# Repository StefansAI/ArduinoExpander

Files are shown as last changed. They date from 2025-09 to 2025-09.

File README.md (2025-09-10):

<h1 style="text-align: center;">ArduinoExpander</h1>
<h2 style="text-align: center;">IO Expander for Arduino Uno</h2>
<br>
<div style="text-align: center;">
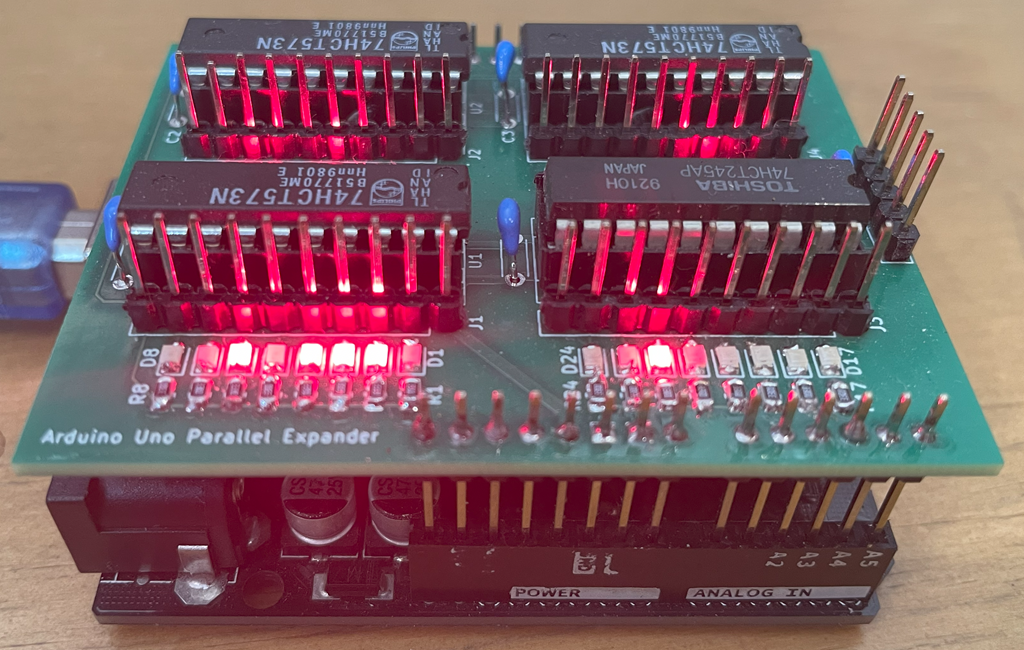
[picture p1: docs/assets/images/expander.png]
  
</div>
<br>
This IO expander plugs into an Arduino Uno to add more controllable pins. It can be used for instance to interact with TTL circuits. One configuration can be 24 bits output and 8 bit bi-directional. Replacing the 74HCT245 chip with a 74HCT573 will give 32 bits output only.
<br><br>
<div style="text-align: center;">
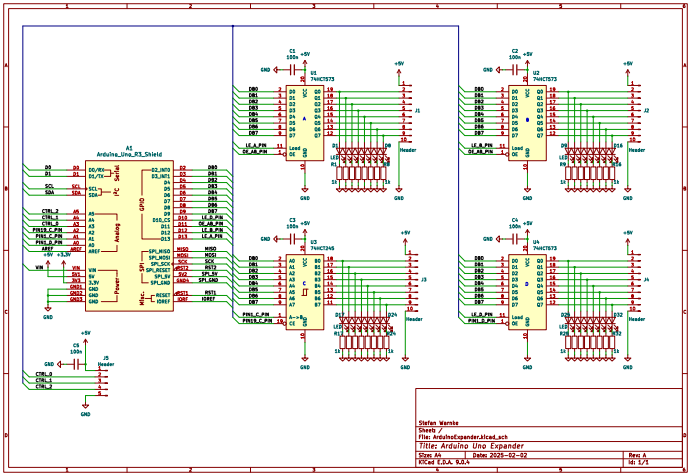
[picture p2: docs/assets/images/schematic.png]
  
</div>
<br>
The schematic and layout are design with KiCad 9.
<br><br>
<div style="text-align: center;">
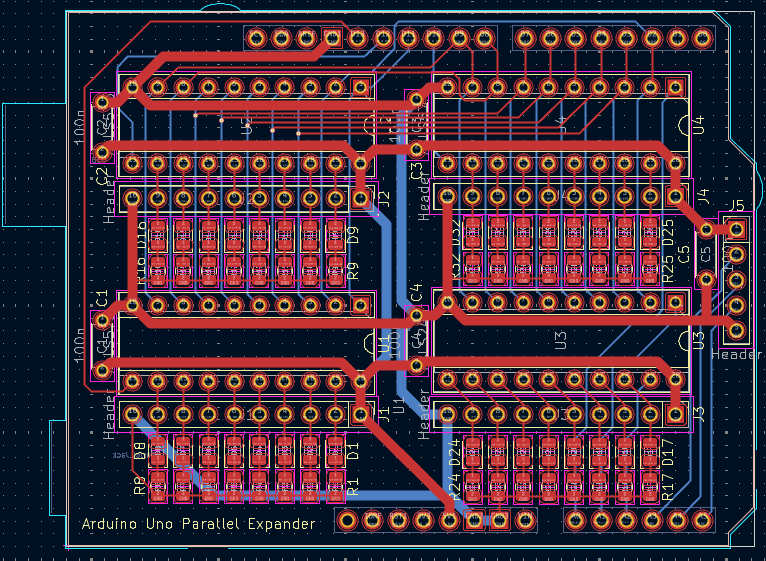
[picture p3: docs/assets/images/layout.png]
  
</div>
<br>

The repository contains an example code to test a RAM chip on a breadboard connected to the expander as address bus, databus and control signals.

<br><br>
<div style="text-align: center;">
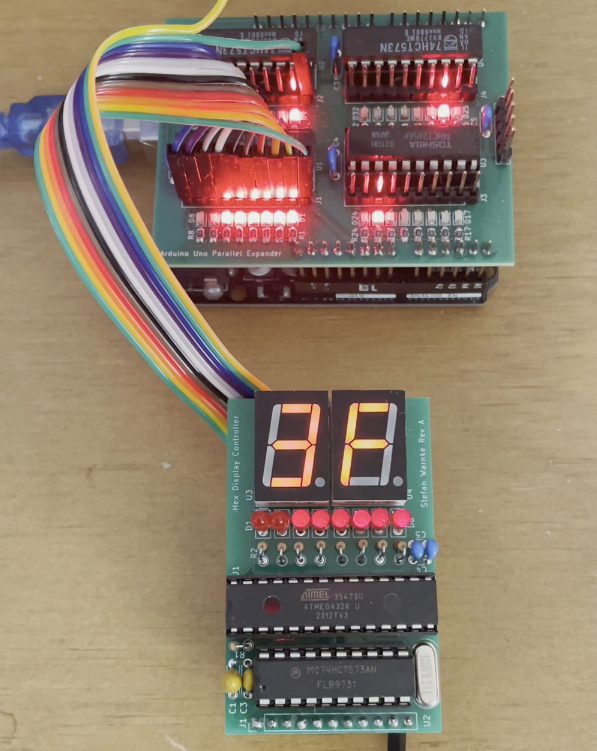
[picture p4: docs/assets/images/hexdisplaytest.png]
  
</div>
<br>
Here is an example to test the HexDisplayController.

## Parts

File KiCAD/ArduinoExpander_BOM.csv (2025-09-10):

Reference | Value | Datasheet | Footprint | Qty | DNP | OrderInfo
A1 | Arduino_Uno_R3_Shield | https://docs.arduino.cc/hardware/uno-rev3 | footprints:Arduino_Uno_R3_Shield | 1 |  | https://www.amazon.com/ELEGOO-Board-ATmega328P-ATMEGA16U2-Compliant/dp/B01EWOE0UU?s=industrial
C1,C2,C3,C4,C5 | 100n | ~ | Capacitor_THT:C_Disc_D4.3mm_W1.9mm_P5.00mm | 5 |  | https://www.digikey.com/en/products/detail/kemet/C320C104M5R5TA/3726028
D1,D2,D3,D4,D5,D6,D7,D8,D9,D10,D11,D12,D13,D14,D15,D16,D17,D18,D19,D20,D21,D22,D23,D24,D25,D26,D27,D28,D29,D30,D31,D32 | LED | ~ | LED_SMD:LED_0805_2012Metric | 32 |  | https://www.digikey.com/en/products/detail/harvatek-corporation/B1701URO-20D000114U1930/16671739
J1,J2,J3,J4,J5 | Header | ~ | Connector_PinHeader_2.54mm:PinHeader_1x05_P2.54mm_Vertical,Connector_PinHeader_2.54mm:PinHeader_1x10_P2.54mm_Vertical | 5
R1,R2,R3,R4,R5,R6,R7,R8,R9,R10,R11,R12,R13,R14,R15,R16,R17,R18,R19,R20,R21,R22,R23,R24,R25,R26,R27,R28,R29,R30,R31,R32 | 1k | ~ | Resistor_SMD:R_0805_2012Metric | 32 |  | https://www.digikey.com/en/products/detail/yageo/RC0805FR-071KL/727444
U1,U2,U4 | 74HCT573 | 74xx/74hc573.pdf | Package_DIP:DIP-20_W7.62mm_Socket | 3 |  | https://www.digikey.com/en/products/detail/texas-instruments/CD74HCT573E/38717
U3 | 74HCT245 | http://www.ti.com/lit/gpn/sn74LS245 | Package_DIP:DIP-20_W7.62mm_Socket | 1 |  | https://www.digikey.com/en/products/detail/texas-instruments/SN74HCT245N/277258

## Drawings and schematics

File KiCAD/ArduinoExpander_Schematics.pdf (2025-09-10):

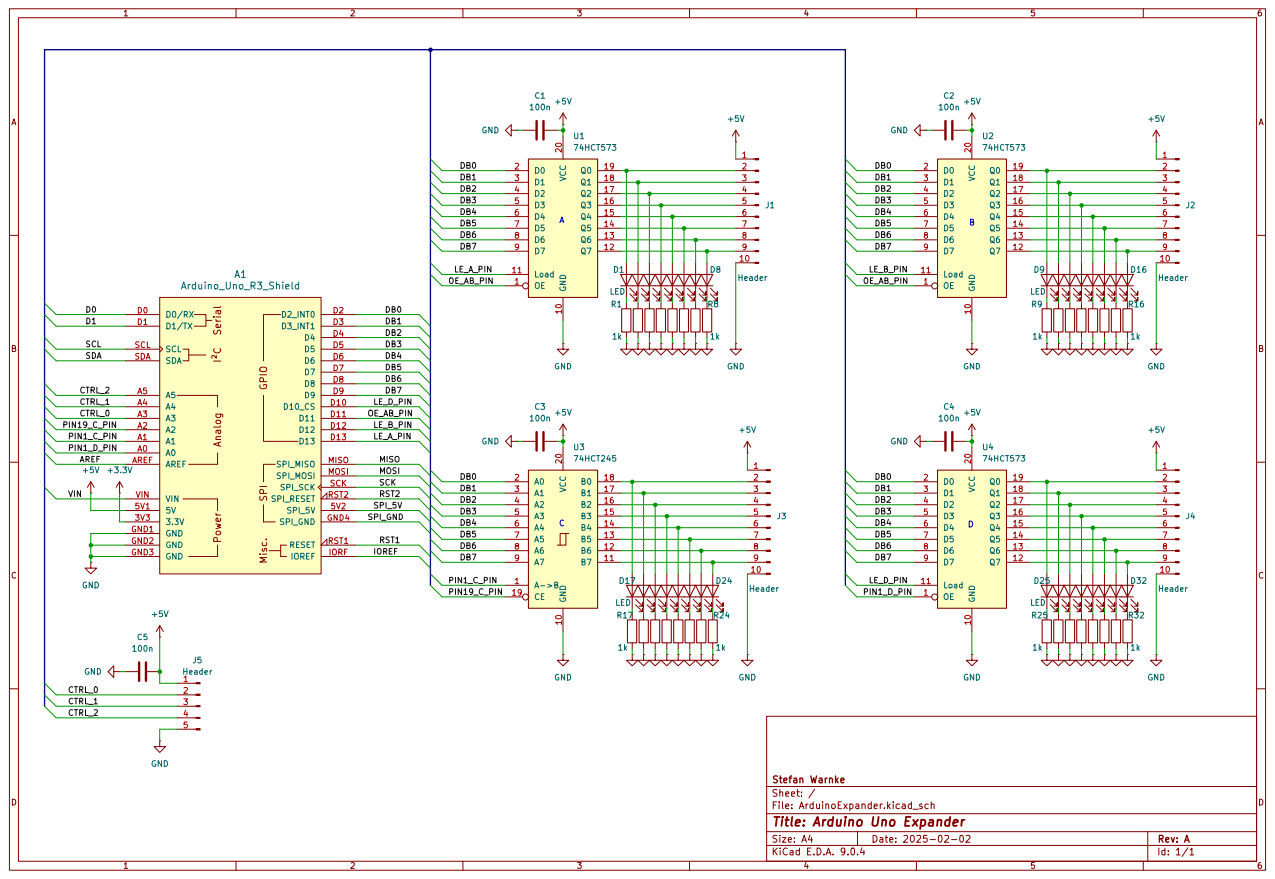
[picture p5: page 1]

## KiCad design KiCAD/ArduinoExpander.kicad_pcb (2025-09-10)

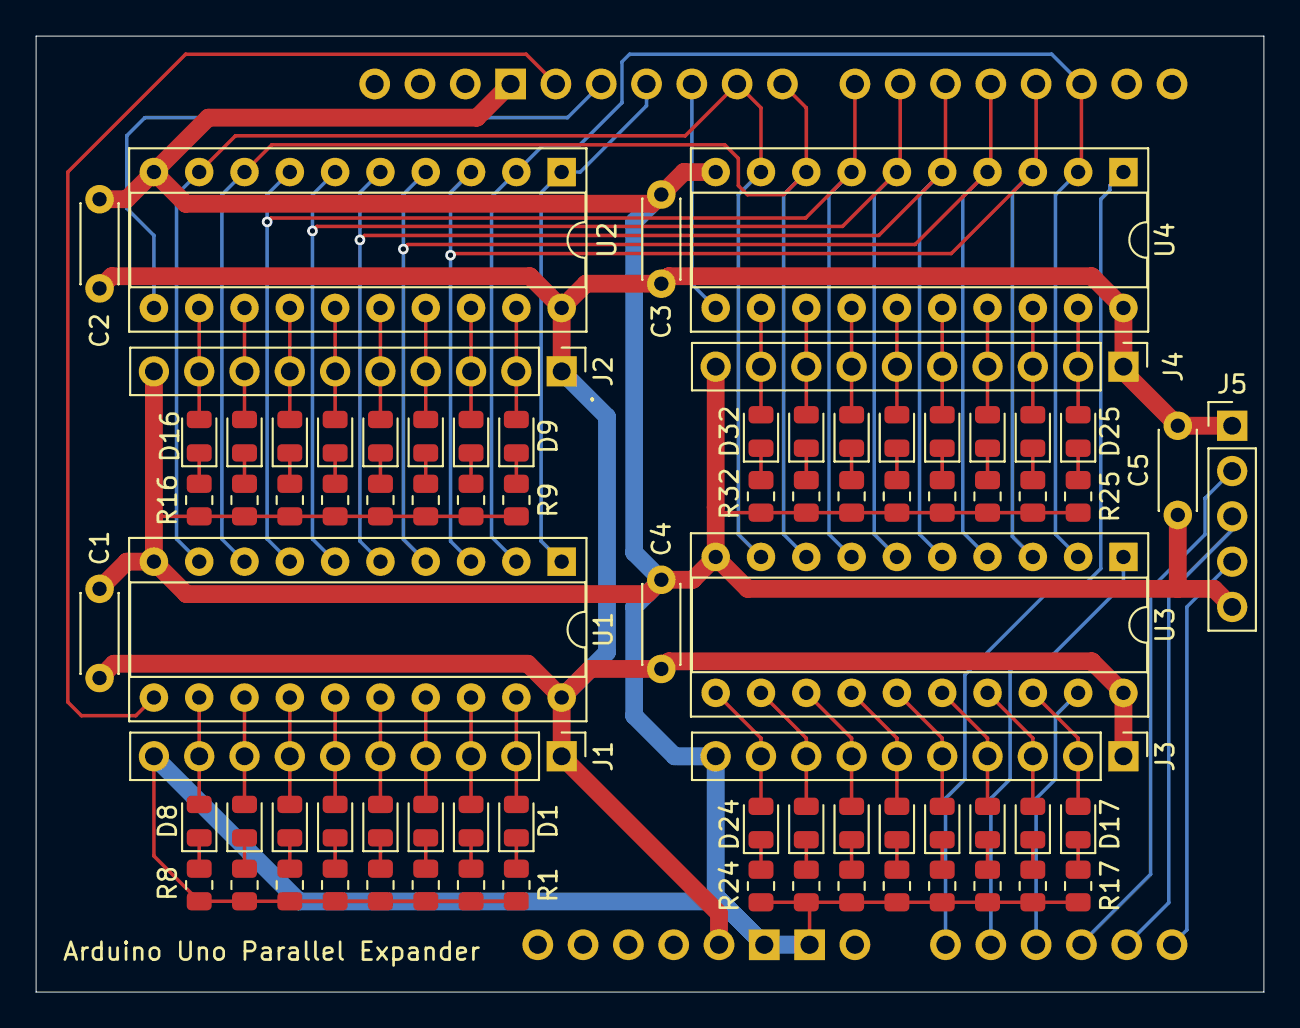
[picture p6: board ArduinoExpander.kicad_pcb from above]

Board: 2 copper layers, 68.8 x 53.6 mm, 79 parts (0 on the bottom side), 84 nets.

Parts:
A1: Arduino_Uno_R3_Shield
C1, C2, C3, C4, C5: 100n; C_Disc_D4.3mm_W1.9mm_P5.00mm
D1, D2, D3, D4, D5, D6, D7, D8, D9, D10, D11, D12, D13, D14, D15, D16, D17, D18, D19, D20, D21, D22, D23, D24, D25, D26, D27, D28, D29, D30, D31, D32: LED; LED_0805_2012Metric
J1, J2, J3, J4: Header; PinHeader_1x10_P2.54mm_Vertical
J5: Header; PinHeader_1x05_P2.54mm_Vertical
R1, R2, R3, R4, R5, R6, R7, R8, R9, R10, R11, R12, R13, R14, R15, R16, R17, R18, R19, R20, R21, R22, R23, R24, R25, R26, R27, R28, R29, R30, R31, R32: 1k; R_0805_2012Metric
U1, U2, U4: 74LS573; DIP-20_W7.62mm_Socket
U3: 74LS245; DIP-20_W7.62mm_Socket

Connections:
+5V: A1.5V1 (5V), C1.2, C2.2, C3.2, C4.2, C5.2, J1.1, J2.1, J3.1, J4.1, J5.1, U1.20 (VCC), U2.20 (VCC), U3.20 (VCC), U4.20 (VCC)
/CTRL_0: A1.A3, J5.2
/CTRL_1: A1.A4, J5.3
/CTRL_2: A1.A5, J5.4
/DB0: A1.D2 (D2_INT0), U1.2 (D0), U2.2 (D0), U3.2 (A0), U4.2 (D0)
/DB1: A1.D3 (D3_INT1), U1.3 (D1), U2.3 (D1), U3.3 (A1), U4.3 (D1)
/DB2: A1.D4, U1.4 (D2), U2.4 (D2), U3.4 (A2), U4.4 (D2)
/DB3: A1.D5, U1.5 (D3), U2.5 (D3), U3.5 (A3), U4.5 (D3)
/DB4: A1.D6, U1.6 (D4), U2.6 (D4), U3.6 (A4), U4.6 (D4)
/DB5: A1.D7, U1.7 (D5), U2.7 (D5), U3.7 (A5), U4.7 (D5)
/DB6: A1.D8, U1.8 (D6), U2.8 (D6), U3.8 (A6), U4.8 (D6)
/DB7: A1.D9, U1.9 (D7), U2.9 (D7), U3.9 (A7), U4.9 (D7)
/LE_A_PIN: A1.D13, U1.11 (Load)
/LE_B_PIN: A1.D12, U2.11 (Load)
/LE_D_PIN: A1.D10 (D10_CS), U4.11 (Load)
/OE_AB_PIN: A1.D11, U1.1 (OE), U2.1 (OE)
/PIN1_C_PIN: A1.A1, U3.1 (A->B)
/PIN1_D_PIN: A1.A0, U4.1 (OE)
/PIN19_C_PIN: A1.A2, U3.19 (CE)
GND: A1.GND1 (GND), A1.GND2 (GND), A1.GND3 (GND), C1.1, C2.1, C3.1, C4.1, C5.1, J1.10, J2.10, J3.10, J4.10, J5.5, R1.2, R2.2, R3.2, R4.2, R5.2, R6.2, R7.2, R8.2, R9.2, R10.2, R11.2, R12.2, R13.2, R14.2, R15.2, R16.2, R17.2, R18.2, R19.2, R20.2, R21.2, R22.2, R23.2, R24.2, R25.2, R26.2, R27.2, R28.2, R29.2, R30.2, R31.2, R32.2, U1.10 (GND), U2.10 (GND), U3.10 (GND), U4.10 (GND)
unnamed: D1.2 (A), J1.2, U1.19 (Q0)
unnamed: D1.1 (K), R1.1
unnamed: D2.2 (A), J1.3, U1.18 (Q1)
unnamed: D2.1 (K), R2.1
unnamed: D3.2 (A), J1.4, U1.17 (Q2)
unnamed: D3.1 (K), R3.1
unnamed: D4.2 (A), J1.5, U1.16 (Q3)
unnamed: D4.1 (K), R4.1
unnamed: D5.2 (A), J1.6, U1.15 (Q4)
unnamed: D5.1 (K), R5.1
unnamed: D6.2 (A), J1.7, U1.14 (Q5)
unnamed: D6.1 (K), R6.1
unnamed: D7.2 (A), J1.8, U1.13 (Q6)
unnamed: D7.1 (K), R7.1
unnamed: D8.2 (A), J1.9, U1.12 (Q7)
unnamed: D8.1 (K), R8.1
unnamed: D9.2 (A), J2.2, U2.19 (Q0)
unnamed: D9.1 (K), R9.1
unnamed: D10.2 (A), J2.3, U2.18 (Q1)
unnamed: D10.1 (K), R10.1
unnamed: D11.2 (A), J2.4, U2.17 (Q2)
unnamed: D11.1 (K), R11.1
unnamed: D12.2 (A), J2.5, U2.16 (Q3)
unnamed: D12.1 (K), R12.1
unnamed: D13.2 (A), J2.6, U2.15 (Q4)
unnamed: D13.1 (K), R13.1
unnamed: D14.2 (A), J2.7, U2.14 (Q5)
unnamed: D14.1 (K), R14.1
unnamed: D15.2 (A), J2.8, U2.13 (Q6)
unnamed: D15.1 (K), R15.1
unnamed: D16.2 (A), J2.9, U2.12 (Q7)
unnamed: D16.1 (K), R16.1
unnamed: D17.2 (A), J3.2, U3.18 (B0)
unnamed: D17.1 (K), R17.1
unnamed: D18.2 (A), J3.3, U3.17 (B1)
unnamed: D18.1 (K), R18.1
unnamed: D19.2 (A), J3.4, U3.16 (B2)
unnamed: D19.1 (K), R19.1
unnamed: D20.2 (A), J3.5, U3.15 (B3)
unnamed: D20.1 (K), R20.1
unnamed: D21.2 (A), J3.6, U3.14 (B4)
unnamed: D21.1 (K), R21.1
unnamed: D22.2 (A), J3.7, U3.13 (B5)
unnamed: D22.1 (K), R22.1
unnamed: D23.2 (A), J3.8, U3.12 (B6)
unnamed: D23.1 (K), R23.1
unnamed: D24.2 (A), J3.9, U3.11 (B7)
unnamed: D24.1 (K), R24.1
unnamed: D25.2 (A), J4.2, U4.19 (Q0)
unnamed: D25.1 (K), R25.1
unnamed: D26.2 (A), J4.3, U4.18 (Q1)
unnamed: D26.1 (K), R26.1
unnamed: D27.2 (A), J4.4, U4.17 (Q2)
unnamed: D27.1 (K), R27.1
unnamed: D28.2 (A), J4.5, U4.16 (Q3)
unnamed: D28.1 (K), R28.1
unnamed: D29.2 (A), J4.6, U4.15 (Q4)
unnamed: D29.1 (K), R29.1
unnamed: D30.2 (A), J4.7, U4.14 (Q5)
unnamed: D30.1 (K), R30.1
unnamed: D31.2 (A), J4.8, U4.13 (Q6)
unnamed: D31.1 (K), R31.1
unnamed: D32.2 (A), J4.9, U4.12 (Q7)
unnamed: D32.1 (K), R32.1

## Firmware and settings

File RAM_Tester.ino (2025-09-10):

// ================================================
//
// SPDX-FileCopyrightText: 2025 Stefan Warnke
//
// SPDX-License-Identifier: BeerWare
//
//=================================================
//
// File:  RAM_Tester
// 
// The code can be used to test a number of 
// different circuitries, like logic chips, RAMs, 
// ROMs etc with the Arduino ExpansionBoard
//
//=================================================

// General ExpansionBoard pin definitions
//---------------------------------------
// Definition of the D0 pin
const int DATA_PIN_D0 = 2;
// Output enable for AB outputs
const int OE_AB_PIN = 11;
// Latch enable for A register
const int LE_A_PIN = 13;
// Latch enable for B register
const int LE_B_PIN = 12;
// Output enable for D register
const int PIN1_D_PIN = A0;   
// Direction signal for 74HCT245 type chip
const int PIN1_C_PIN = A1;   
// Output enable for C register or 74HCT245 buffer
const int PIN19_C_PIN = A2;   
// Latch enable for D register
const int LE_D_PIN = 10; 
// J5 Header control line 0     
const int CTRL_0 = A3;   
// J5 Header control line 1    
const int CTRL_1 = A4;   
// J5 Header control line 2
const int CTRL_2 = A5;    

// RAM tester specific pin definitions
//---------------------------------------
// RAM Write Enable pin
const int WE_PIN = CTRL_0; 
// RAM Chip Select pin    
const int CS_PIN = CTRL_1;    
// RAM Output Enable pin 
const int OE_PIN = CTRL_2;      

// Masks to set or reset the control signals
const int RAM_CS_H = 1<<0;
const int RAM_OE_H = 1<<1;
const int RAM_WE_H = 1<<2;
const int RAM_CS_L = 0;
const int RAM_OE_L = 0;
const int RAM_WE_L = 0;

// Example max addr for a HM62256
const int MAX_ADDR = (1<<15)-1;

// Buffer for sprintf
char buff[100];
// Variable for address output
int addr = 0; //0x33A0;
// Variable for data output 
int wr_data = 0;
// Variable for data input
int rd_data = 0;
// Cycle counter
int cycle = 0;
// Control signals
int ctrl = 0;

// Set the 8 bit data output for any register
void set_data(int value)
{
  for (int i=0; i<8; i++)
  {
    if ((value & 1) == 0)
      digitalWrite(DATA_PIN+i, LOW);
    else
      digitalWrite(DATA_PIN+i, HIGH);
    value >>= 1;
  }
}

// Read data input
int get_data()
{
  int result=0;
  for (int i=0; i<8; i++)
  {
    int value = digitalRead(DATA_PIN+i);
    if (value == HIGH)
      result += 1<<i;    
  }
  return result;
}

// Set data to output mode
void set_data_out()
{
   for (int i=DATA_PIN; i<DATA_PIN+8; i++)
      pinMode(i, OUTPUT);  
}

// Set data to input mode
void set_data_in()
{
  for (int i=DATA_PIN; i<DATA_PIN+8; i++)
      pinMode(i, INPUT);  
}

// Set the pin output level
void set_pin_out(int pin, int level)
{
  pinMode(pin, OUTPUT);
  digitalWrite(pin, level);
}

// Write a value to the A register
void set_A(int value)
{
  set_data_out();
  set_data(value);
  digitalWrite(LE_A_PIN, HIGH);
  digitalWrite(LE_A_PIN, LOW);
  digitalWrite(OE_AB_PIN, LOW);
}

// Write a value to the B register
void set_B(int value)
{
  set_data_out();
  set_data(value);
  digitalWrite(LE_B_PIN, HIGH);
  digitalWrite(LE_B_PIN, LOW);
  digitalWrite(OE_AB_PIN, LOW);
}

// Write a value to the D register
void set_D(int value)
{
  set_data_out();
  set_data(value);
  digitalWrite(LE_D_PIN, HIGH);
  digitalWrite(LE_D_PIN, LOW);
  digitalWrite(PIN1_D_PIN, LOW);
}

// Write a value to the C channel (DB)
void set_Cout(int value)
{
  set_data_out();
  set_data(value);
  digitalWrite(PIN1_C_PIN, HIGH);
  digitalWrite(PIN19_C_PIN, LOW);
}

// Read a value from the C channel (DB)
int get_Cin()
{
  set_data_in();
  digitalWrite(PIN1_C_PIN, LOW);
  digitalWrite(PIN19_C_PIN, LOW);
  int result = get_data();
  digitalWrite(PIN19_C_PIN, HIGH);
  return result;
}

// Setup the pins for the main loop
void setup() 
{
  Serial.begin(9600);
  set_data_out();
  set_pin_out(OE_AB_PIN, HIGH);
  set_pin_out(LE_A_PIN, HIGH);
  set_pin_out(LE_B_PIN, HIGH);
  set_pin_out(PIN1_D_PIN, HIGH);
  set_pin_out(PIN1_C_PIN, HIGH);
  set_pin_out(PIN19_C_PIN, HIGH);
  set_pin_out(LE_D_PIN, HIGH);
  set_pin_out(WE_PIN,HIGH);
  set_pin_out(CS_PIN,HIGH);
  set_pin_out(OE_PIN,HIGH);

/*WritePattern();

    digitalWrite(PIN19_C_PIN, HIGH);
    set_D(RAM_CS_H | RAM_OE_H | RAM_WE_H);
    set_A(addr & 0xFF);
    set_B(addr >> 8);
    set_Cout(wr_data);
*/
  Serial.println("Setup Done");
}

#define TIME 1000

// Write a pseudo random pattern
void WritePattern()
{
  sprintf(buff,"Writing cycle=%d", cycle); 
  Serial.println(buff);

  for (addr=0; addr<MAX_ADDR; addr++)
  {
     wr_data = ((addr & 0xFF)) ^ (addr >> 8) ^ cycle) & 0xFF;
    //wr_data = 1<<(i & 7);
 
    //sprintf(buff,"Writing cycle=%d  addr=%04X  wr_data=%02X", cycle, addr, wr_data); 
    //Serial.println(buff);

    digitalWrite(PIN19_C_PIN, HIGH);
    set_A(addr & 0xFF);
    set_B(addr >> 8);
    set_Cout(wr_data);
    digitalWrite(CS_PIN,LOW);
    digitalWrite(WE_PIN,LOW);
    digitalWrite(WE_PIN,HIGH);
    digitalWrite(CS_PIN,HIGH);
    digitalWrite(PIN19_C_PIN, HIGH);
    //delay(TIME);
  }
}

// Read and check the pseudo random pattern
void CheckPattern()
{
  Serial.println("Loop Reading");

  for (addr=0; addr<MAX_ADDR; addr++)
  {
    wr_data = ((addr & 0xFF)) ^ (addr >> 8) ^ cycle) &0xFF;
    //wr_data = 1<<(addr & 7);
 
    digitalWrite(PIN19_C_PIN, HIGH);
    set_A(addr & 0xFF);
    set_B(addr >> 8);
    digitalWrite(CS_PIN,LOW);
    digitalWrite(OE_PIN,LOW);
    rd_data = get_Cin();
    digitalWrite(OE_PIN,HIGH);
    digitalWrite(CS_PIN,HIGH);
    if (rd_data != wr_data)
    {
      sprintf(buff,"Reading cycle=%d  addr=%04X  wr_data=%02X  rd_data=%02X", cycle, addr, wr_data, rd_data); 
      Serial.println(buff);
      delay(TIME);
    }
  }
}


// Another way of testing
void Test1()
{
  sprintf(buff,"addr=%04X", addr); 
  Serial.println(buff);
  set_A(addr & 0xFF);
  set_B(addr >> 8);
  set_D(ctrl);
  set_Cout(wr_data);
  delay(500);
  ctrl = ctrl >> 1;
  if ((ctrl & 0xFF) == 0)
    ctrl = 0x80;
  wr_data = wr_data << 1;
  if ((wr_data & 0xFF) == 0)
    wr_data = 1;
  addr=addr+1;
}

// Another possible Test run
void Test1()
{

  //set_D(RAM_CS_H | RAM_OE_H | RAM_WE_H);
  //rd_data = get_Cin();

  for (i=0; i<8; i++)
  {
    wr_data = 1<<(i & 7);

      sprintf(buff,"Writing cycle=%d  wr_data=%02X", cycle, wr_data); 
      Serial.println(buff);

    set_Cout(wr_data);
    delay(TIME);
    
    rd_data = get_Cin();

      sprintf(buff,"Reading cycle=%d  rd_data=%02X", cycle, rd_data); 
      Serial.println(buff);

    delay(TIME);
  }
}

// Main loop
void loop() 
{
  WritePattern();
  CheckPattern();
   cycle++;
}
